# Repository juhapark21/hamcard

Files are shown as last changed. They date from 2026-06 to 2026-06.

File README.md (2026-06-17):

# Ham radio card 
A small dashboard that displays propagation conditions with colored LEDs. 

SS 2026-06-11 at 5 26 39 PM
SS 2026-06-11 at 5 27 05 PM
SS 2026-06-11 at 5 27 47 PM

## How to use 
Replace the placeholder values in the firmware with the SSID and password of your known wifi network. This makes it so that the microcontroller can connect to a network and access the weather data online.  

Assemble the PCB. Components are sized to be possible to hand-solder - A few components are through-hole for ease of hand-soldering.  

After assembling the PCB, flash the firmware onto the XIAO ESP32C3 ([instructions here](https://wiki.seeedstudio.com/xiao_esp32c3_with_micropython/)). 

Connect the ESP32 to a power source via USB-C and turn the power switch ON. The indicator light on the bottom right corner will turn on. 

As long as the board is connected to a network and a power source, it will update its data every hour and the indicator lights will change accordingly. 

LED indicator lights ordered by general severity: 
- Green: Good-Great
- Yellow: Fair
- Orange: Fair-Poor
- Red: Poor 

To turn off, turn the power switch OFF then disconnect the board from the power source. 

## Why 
Propagation info like this is like the weather report for radio nerds. It helps determine which bands you should work, or approximately how far your signal will reach. 

I initially made it because I wanted a fun useful business card. That idea got a bit out of hand (the thickness and power consumption of this does not make it very suitable to be used as a card), but I ended up with a nice physical dashboard showing useful weather information for amateur radio. 

Most existing dashboards are online, so I wanted this to be a physical object separate from tabs or apps on my computer. 

## Process 
The design and build process is documented in detail [here](https://fallout.hackclub.com/projects/3668). Even though this project was smaller-scale, it involved a lot of trial-and-error. 

## Credits  
Thank you Paul N0NBH for the solar-terrestrial [data](https://www.hamqsl.com/).  

## Zine page 
Zine - radiocard

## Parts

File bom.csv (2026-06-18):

Index | Quantity | Part Number | Manufacturer Part Number | Description | Link | Available | Backorder | Unit Price | Extended Price USD
1 | 1 | 1597-113991054-ND | 113991054 | XIAO ESP32C3 | https://www.digikey.com/en/products/detail/seeed-technology-co-ltd/113991054/16652880 | 1 | 0 | 4.99000 | 4.99
2 | 2 | 2057-PH1-07-UA-ND | PH1-07-UA | CONN HEADER VERT 7POS 2.54MM | https://www.digikey.com/en/products/detail/adam-tech/PH1-07-UA/9830505 | 2 | 0 | 0.10000 | 0.20
3 | 4 | 1727-2821-1-ND | 74HC595D,118 | IC SHFT REG TRI-STATE 8BIT 16-SO | https://www.digikey.com/en/products/detail/nexperia-usa-inc/74HC595D-118/763087 | 4 | 0 | 0.25000 | 1.00
4 | 1 | 2223-SLW-883935-2A-D-ND | SLW-883935-2A-D | SWITCH SLIDE SPDT 0.5A 30V | https://www.digikey.com/en/products/detail/same-sky-formerly-cui-devices/SLW-883935-2A-D/21259966 | 1 | 0 | 0.47000 | 0.47
5 | 13 | RNCP1206FTD100RCT-ND | RNCP1206FTD100R | RES 100 OHM 1% 1/2W 1206 | https://www.digikey.com/en/products/detail/stackpole-electronics-inc/RNCP1206FTD100R/2240316 | 13 | 0 | 0.01800 | 0.23
6 | 4 | 399-C1206C104K5RACTUCT-ND | C1206C104K5RACTU | CAP CER 0.1UF 50V X7R 1206 | https://www.digikey.com/en/products/detail/kemet/C1206C104K5RACTU/411248 | 4 | 0 | 0.11000 | 0.44
7 | 3 | 160-1406-1-ND | LTST-C150KSKT | LED YELLOW CLEAR 1206 SMD | https://www.digikey.com/en/products/detail/liteon/LTST-C150KSKT/386763 | 3 | 0 | 0.14000 | 0.42
8 | 3 | 160-1405-1-ND | LTST-C150KRKT | LED RED CLEAR 1206 SMD | https://www.digikey.com/en/products/detail/liteon/LTST-C150KRKT/386761 | 3 | 0 | 0.15000 | 0.45
9 | 3 | 160-1403-1-ND | LTST-C150KFKT | LED ORANGE CLEAR 1206 SMD | https://www.digikey.com/en/products/detail/liteon/LTST-C150KFKT/386758 | 3 | 0 | 0.15000 | 0.45
10 | 4 | 160-1404-1-ND | LTST-C150KGKT | LED GREEN CLEAR 1206 SMD | https://www.digikey.com/en/products/detail/liteon/LTST-C150KGKT/365085 | 4 | 0 | 0.16000 | 0.64
11 | 10 | 160-1172-1-ND | LTST-C155GEKT | LED GREEN/RED CLEAR CHIP SMD | https://www.digikey.com/en/products/detail/liteon/LTST-C155GEKT/269219 | 10 | 0 | 0.15300 | 1.53
12 | 16 | RNCP1206FTD200RCT-ND | RNCP1206FTD200R | RES 200 OHM 1% 1/2W 1206 | https://www.digikey.com/en/products/detail/stackpole-electronics-inc/RNCP1206FTD200R/2240320 | 16 | 0 | 0.01800 | 0.29
Total cost |  |  |  |  |  |  |  |  | 11.11

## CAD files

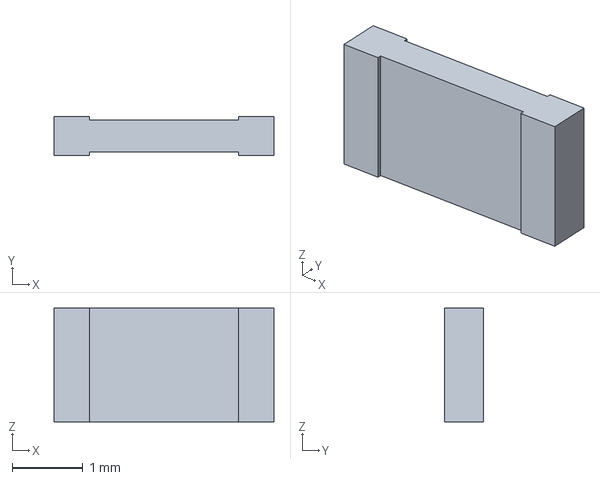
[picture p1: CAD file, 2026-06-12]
pcb/ProjectSpecificResources/crm1206.stp
3.10 x 0.55 x 1.60 mm

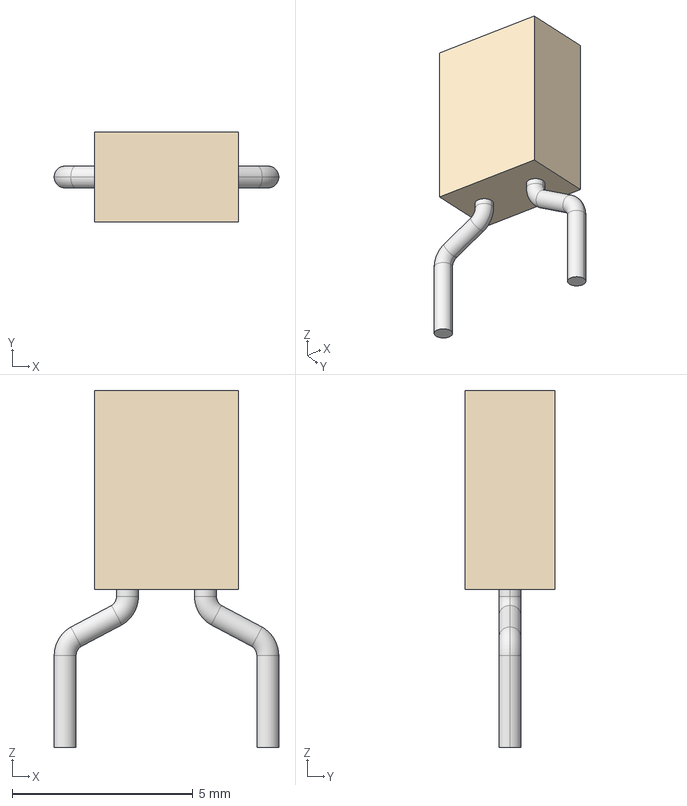
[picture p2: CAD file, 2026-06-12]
pcb/ProjectSpecificResources/CAP_FG28_TDK.step
6.22 x 2.49 x 9.88 mm

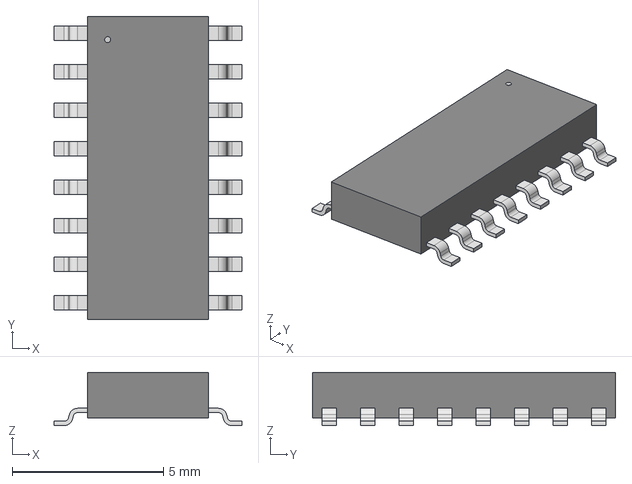
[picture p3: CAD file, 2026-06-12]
pcb/ProjectSpecificResources/SOT109-1_NXP.step
6.20 x 10.0 x 1.75 mm

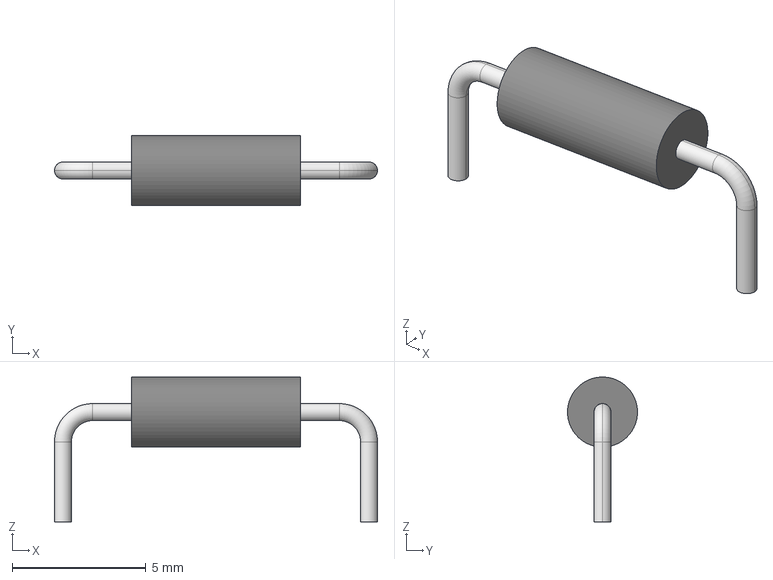
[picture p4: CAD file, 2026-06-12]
pcb/ProjectSpecificResources/STA_CFM12_STP.step
12.1 x 2.61 x 5.41 mm

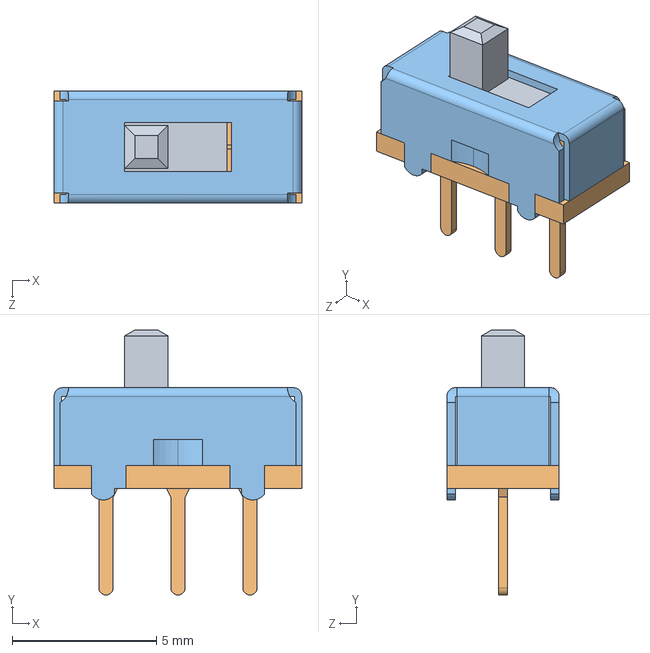
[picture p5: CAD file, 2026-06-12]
pcb/ProjectSpecificResources/Same_Sky_SLW-883935-2A-D.step
8.60 x 9.20 x 3.90 mm

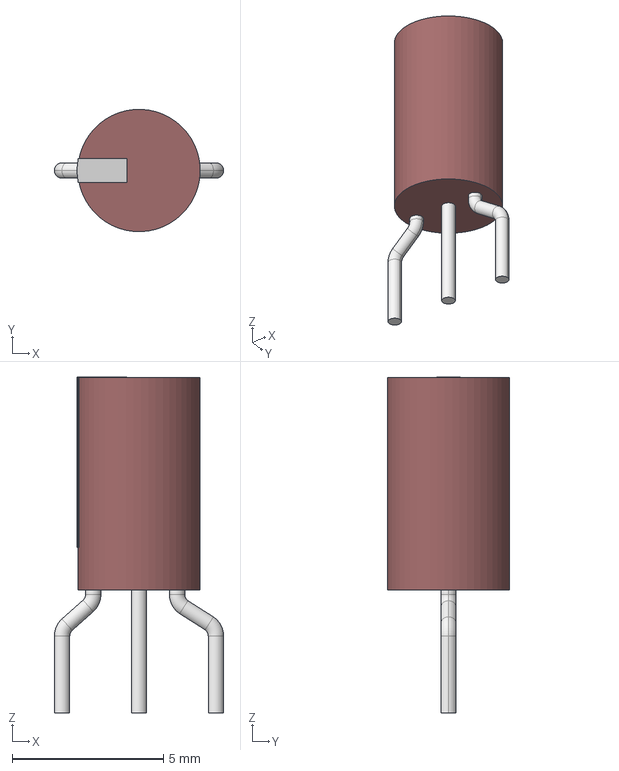
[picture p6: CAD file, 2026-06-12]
pcb/ProjectSpecificResources/LTL-LED3_LTO.step
5.59 x 4.04 x 11.1 mm

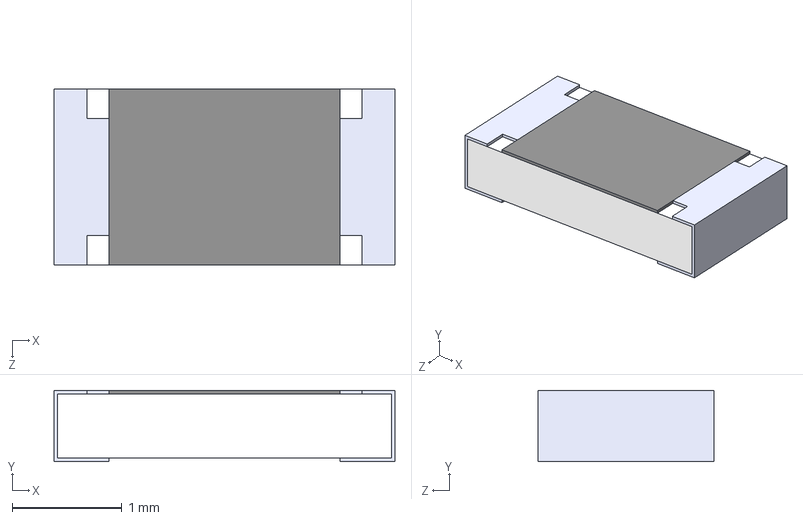
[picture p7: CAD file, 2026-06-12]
pcb/ProjectSpecificResources/CRM1206-FX-33R0ELF.step
3.10 x 0.65 x 1.60 mm

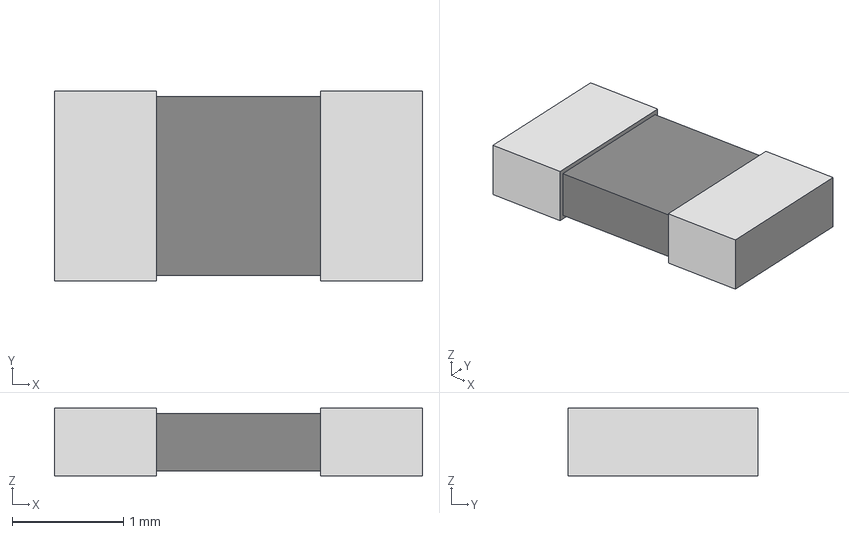
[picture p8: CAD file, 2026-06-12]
pcb/ProjectSpecificResources/STA_RNCP1206_STP.step
3.30 x 1.70 x 0.61 mm

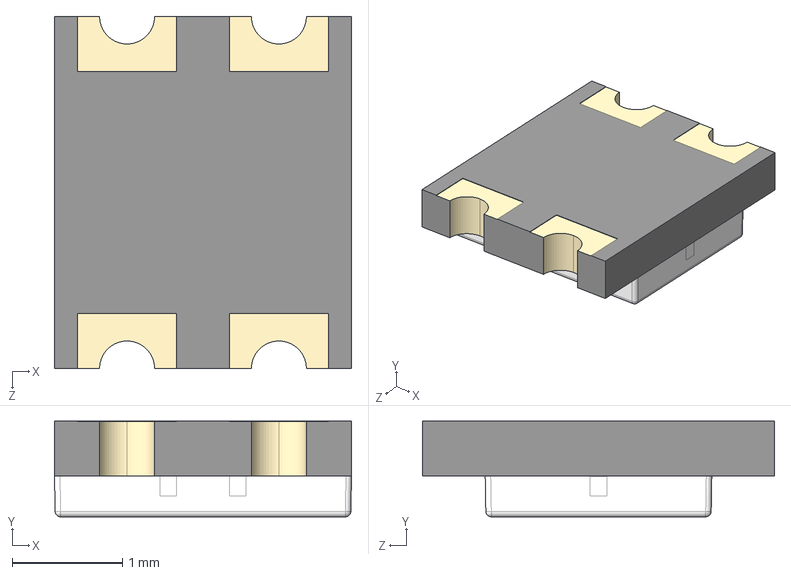
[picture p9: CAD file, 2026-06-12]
pcb/ProjectSpecificResources/LTST-C155GEKT.stp
2.70 x 0.87 x 3.20 mm

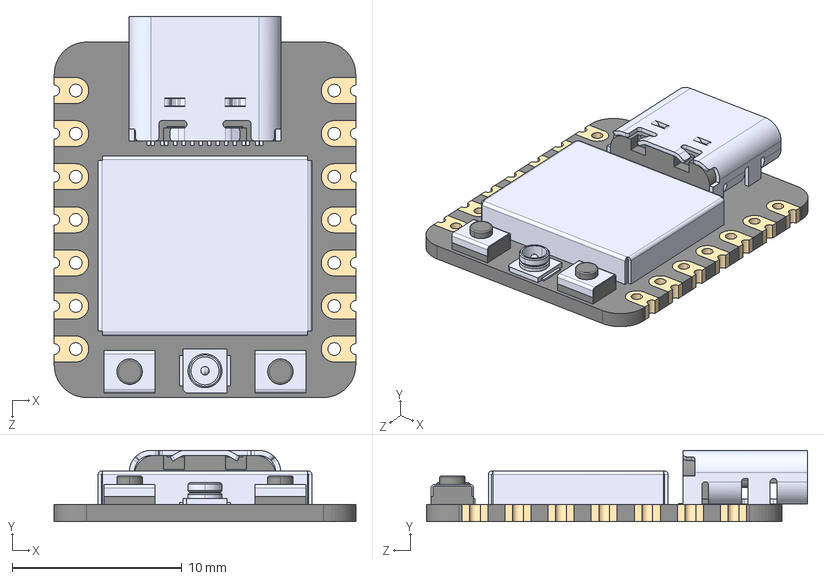
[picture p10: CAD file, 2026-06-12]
pcb/ProjectSpecificResources/113991054.STEP
17.8 x 4.21 x 22.5 mm

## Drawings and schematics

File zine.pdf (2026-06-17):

# HAM RADIO (BUSINESS) CARD!!

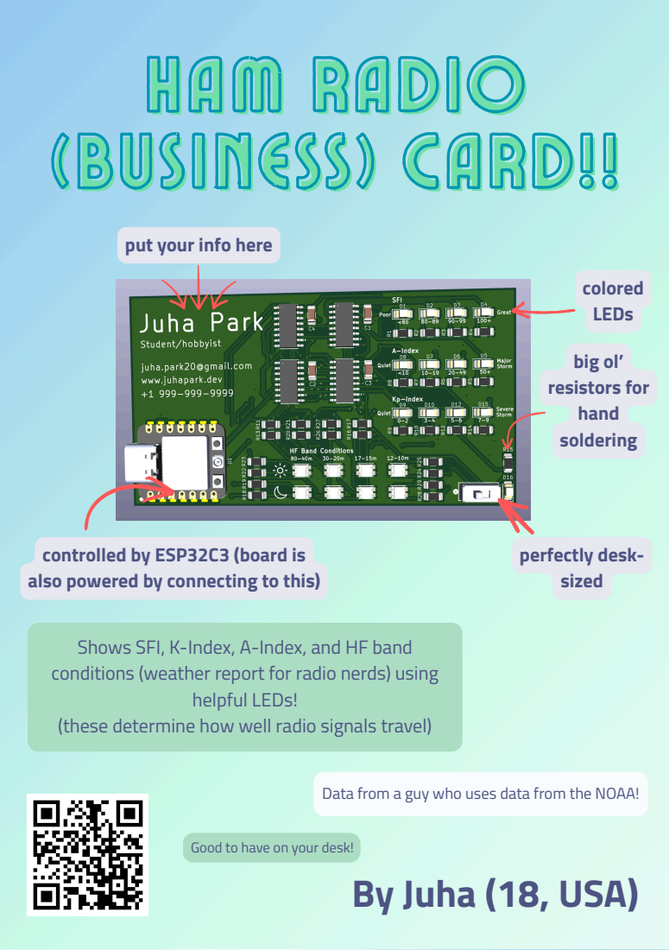
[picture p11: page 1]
colored LEDs; big ol’ resistors for hand soldering; perfectly desk- sized; helpful LEDs!; HHAAMM RRAADDIIOO ((BBUUSSIINNEESSSS)) CCAARRDD!!!!

put your info here

controlled by ESP32C3 (board is
also powered by connecting to this)

Shows SFI, K-Index, A-Index, and HF band
conditions (weather report for radio nerds) using

(these determine how well radio signals travel)

Data from a guy who uses data from the NOAA!
By Juha (18, USA)

Good to have on your desk!

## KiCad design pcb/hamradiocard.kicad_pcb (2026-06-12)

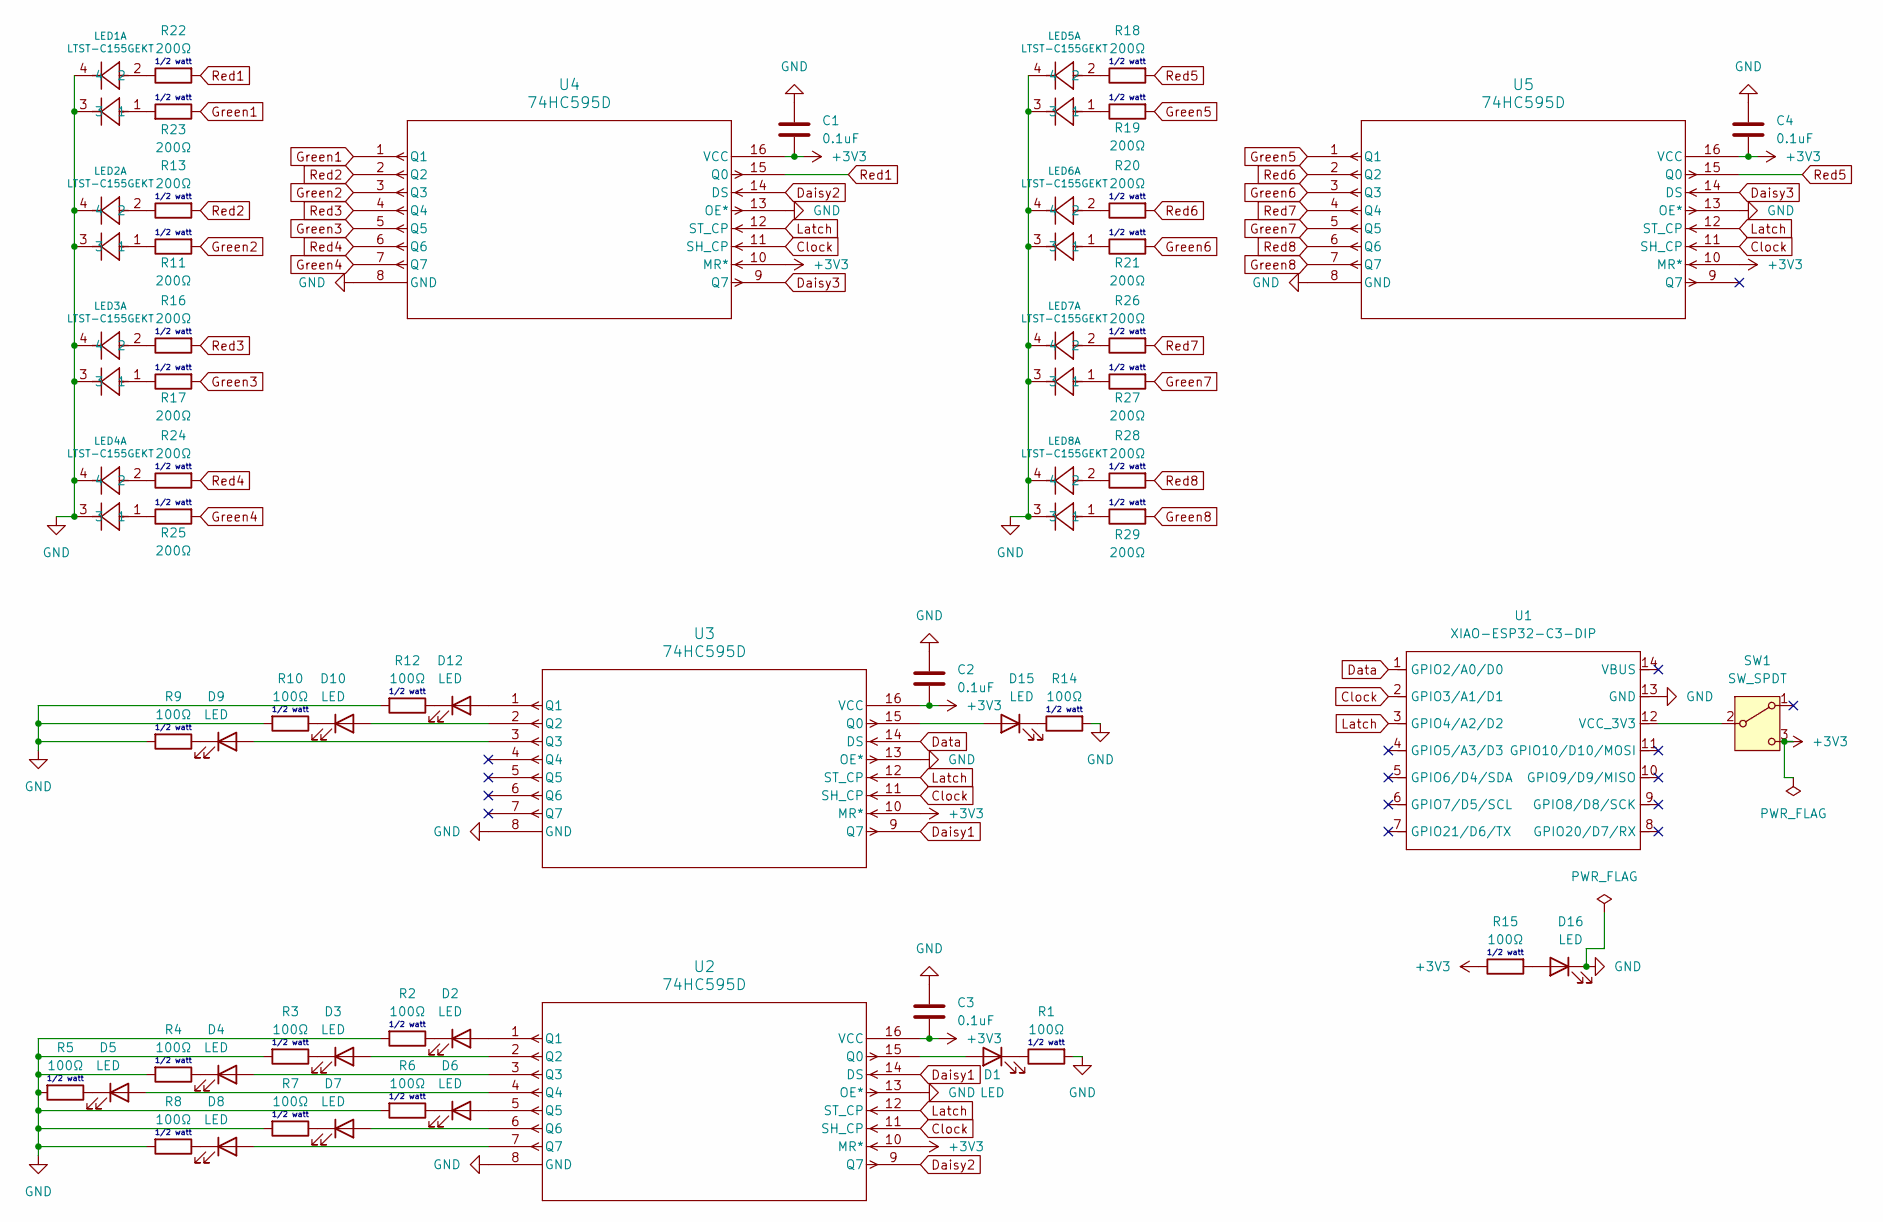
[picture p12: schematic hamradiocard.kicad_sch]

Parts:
C1, C2, C3, C4: 0.1uF; C_1206_3216Metric_Pad1.33x1.80mm_HandSolder
D1, D2, D3, D4, D5, D6, D7, D8, D9, D10, D12, D15, D16: LED; LED_1206_3216Metric_Pad1.42x1.75mm_HandSolder
LED1, LED2, LED3, LED4, LED5, LED6, LED7, LED8: LTST-C155GEKT; DIODE_LTST-C155GEKT_LTO-M
R1, R2, R3, R4, R5, R6, R7, R8, R9, R10, R12, R14, R15: 100Ω; R_1206_3216Metric_Pad1.30x1.75mm_HandSolder
R11, R13, R16, R17, R18, R19, R20, R21, R22, R23, R24, R25, R26, R27, R28, R29: 200Ω; R_1206_3216Metric_Pad1.30x1.75mm_HandSolder
SW1: SW_SPDT; SW3_SLW-883935-2A-D_SSY
U1: XIAO-ESP32-C3-DIP; XIAO-ESP32C3-DIP
U2, U3, U4, U5: 74HC595D; SOT109-1_NXP

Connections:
+3V3: C1.2, C2.2, C3.2, C4.2, R15.1, SW1.3 (C), U2.10 (MR*), U2.16 (VCC), U3.10 (MR*), U3.16 (VCC), U4.10 (MR*), U4.16 (VCC), U5.10 (MR*), U5.16 (VCC)
Clock: U1.2 (GPIO3/A1/D1), U2.11 (SH_CP), U3.11 (SH_CP), U4.11 (SH_CP), U5.11 (SH_CP)
Daisy1: U2.14 (DS), U3.9 (Q7)
Daisy2: U2.9 (Q7), U4.14 (DS)
Daisy3: U4.9 (Q7), U5.14 (DS)
Data: U1.1 (GPIO2/A0/D0), U3.14 (DS)
GND: C1.1, C2.1, C3.1, C4.1, D16.1 (K), LED1.3, LED1.4, LED2.3, LED2.4, LED3.3, LED3.4, LED4.3, LED4.4, LED5.3, LED5.4, LED6.3, LED6.4, LED7.3, LED7.4, LED8.3, LED8.4, R1.2, R2.2, R3.2, R4.2, R5.2, R6.2, R7.2, R8.2, R9.2, R10.2, R12.2, R14.2, U1.13 (GND), U2.8 (GND), U2.13 (OE*), U3.8 (GND), U3.13 (OE*), U4.8 (GND), U4.13 (OE*), U5.8 (GND), U5.13 (OE*)
Green1: R23.1, U4.1 (Q1)
Green2: R11.2, U4.3 (Q3)
Green3: R17.2, U4.5 (Q5)
Green4: R25.2, U4.7 (Q7)
Green5: R19.2, U5.1 (Q1)
Green6: R21.2, U5.3 (Q3)
Green7: R27.2, U5.5 (Q5)
Green8: R29.2, U5.7 (Q7)
Latch: U1.3 (GPIO4/A2/D2), U2.12 (ST_CP), U3.12 (ST_CP), U4.12 (ST_CP), U5.12 (ST_CP)
unnamed: D1.2 (A), U2.15 (Q0)
unnamed: D1.1 (K), R1.1
unnamed: D2.2 (A), U2.1 (Q1)
unnamed: D2.1 (K), R2.1
unnamed: D3.2 (A), U2.2 (Q2)
unnamed: D3.1 (K), R3.1
unnamed: D4.2 (A), U2.3 (Q3)
unnamed: D4.1 (K), R4.1
unnamed: D5.2 (A), U2.4 (Q4)
unnamed: D5.1 (K), R5.1
unnamed: D6.2 (A), U2.5 (Q5)
unnamed: D6.1 (K), R6.1
unnamed: D7.2 (A), U2.6 (Q6)
unnamed: D7.1 (K), R7.1
unnamed: D8.2 (A), U2.7 (Q7)
unnamed: D8.1 (K), R8.1
unnamed: D9.2 (A), U3.3 (Q3)
unnamed: D9.1 (K), R9.1
unnamed: D10.2 (A), U3.2 (Q2)
unnamed: D10.1 (K), R10.1
unnamed: D12.2 (A), U3.1 (Q1)
unnamed: D12.1 (K), R12.1
unnamed: D15.2 (A), U3.15 (Q0)
unnamed: D15.1 (K), R14.1
unnamed: D16.2 (A), R15.2
unnamed: LED1.1, R23.2
unnamed: LED1.2, R22.1
unnamed: LED2.1, R11.1
unnamed: LED2.2, R13.1
unnamed: LED3.1, R17.1
unnamed: LED3.2, R16.1
unnamed: LED4.1, R25.1
unnamed: LED4.2, R24.1
unnamed: LED5.1, R19.1
unnamed: LED5.2, R18.1
unnamed: LED6.1, R21.1
unnamed: LED6.2, R20.1
unnamed: LED7.1, R27.1
unnamed: LED7.2, R26.1
unnamed: LED8.1, R29.1
unnamed: LED8.2, R28.1
unnamed: SW1.2 (B), U1.12 (VCC_3V3)
Red1: R22.2, U4.15 (Q0)
Red2: R13.2, U4.2 (Q2)
Red3: R16.2, U4.4 (Q4)
Red4: R24.2, U4.6 (Q6)
Red5: R18.2, U5.15 (Q0)
Red6: R20.2, U5.2 (Q2)
Red7: R26.2, U5.4 (Q4)
Red8: R28.2, U5.6 (Q6)

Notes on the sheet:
1/2 watt

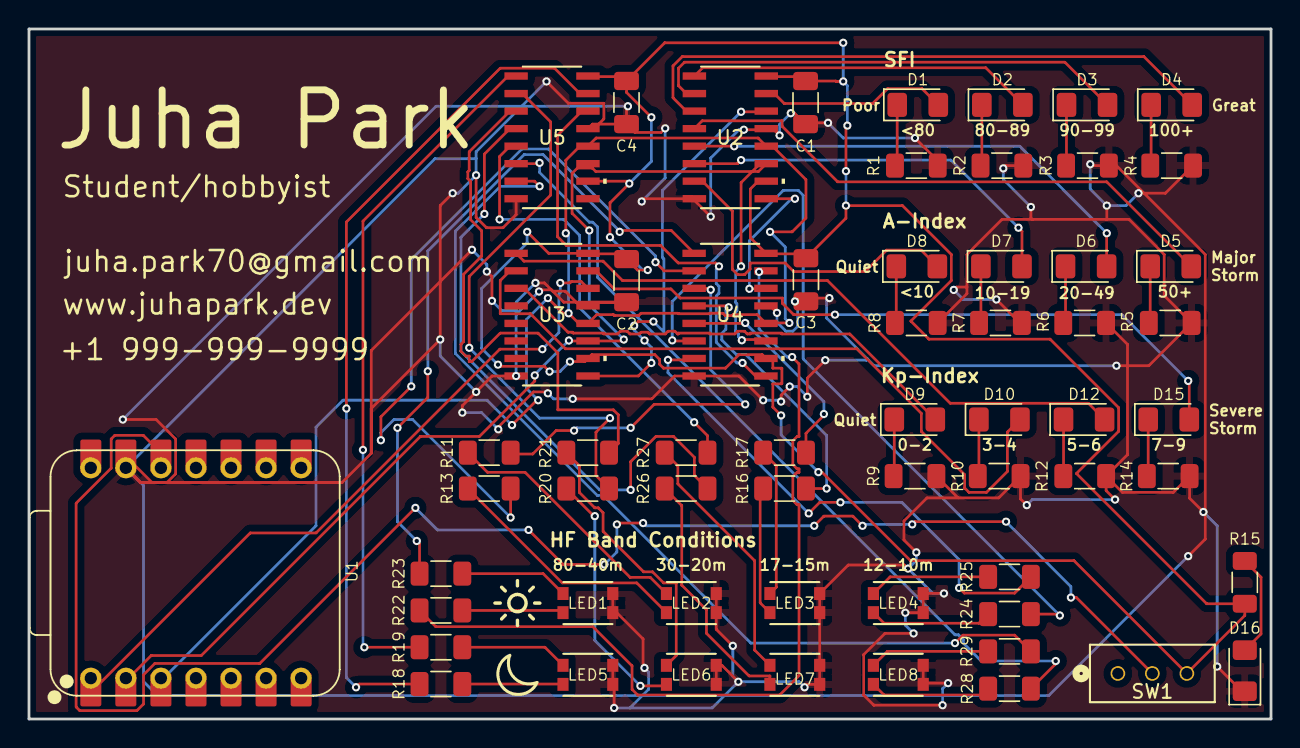
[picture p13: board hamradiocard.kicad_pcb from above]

Board: 2 copper layers, 90.0 x 50.0 mm, 60 parts (0 on the bottom side), 66 nets.

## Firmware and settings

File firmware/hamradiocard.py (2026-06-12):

import network
import time
import requests
from machine import Pin

# https://wiki.seeedstudio.com/xiao_esp32c3_with_micropython/
# will hang until successful connection made 
def do_connect():
    wlan = network.WLAN(network.STA_IF)
    wlan.active(True)
    if not wlan.isconnected():
        print('connecting to network...')
        wlan.connect('SSID', 'KEY') #replace the ssid and key.
        # I really don't want to show my wifi password in my firmware so it's left as a placeholder for now
        while not wlan.isconnected():
            time.sleep(1) 
            pass
    print('network config:', wlan.ifconfig())

def getjson(url):
    response = requests.get(url)
    response_code = response.status_code
    print('Response code: ', response_code)
    response_data = response.json()
    response.close() 
    return response_data  

def getSpecialTagVal(data, start_tag, end_tag):
    try:
        if data.find(start_tag) == -1:
            start_ind = -1
        else: 
            start_ind = data.find(start_tag) + len(start_tag)
        end_ind = data.find(end_tag)
        
        if start_ind != -1 and end_ind != -1:
            value = data[start_ind:end_ind]
            return value
        else:
            print('Tag not found in xml response')
            return -1 
    except Exception as e:
        print('Parsing error: ', e)
        return -1 

def getTagVal(data, tag):
    start_tag = tag
    end_tag = "</" + tag[1:] 
    return getSpecialTagVal(data, start_tag, end_tag)

def getHFVal(data, r, c):
    timeOfDay = ''
    bandnames = {
        0: '80m-40m',
        1: '30m-20m',
        2: '17m-15m',
        3: '12m-10m' 
    }
    
    if r == 0:
        # Daytime
        timeOfDay = 'day'
    else:
        # Nighttime
        timeOfDay = 'night'
    
    longtag = '<band name="' + bandnames[c] + '" time="' + timeOfDay + '">'
    return getSpecialTagVal(data, longtag, '</band>') 

# Set up network connection and pins 
do_connect()

dataPin = Pin(2, Pin.OUT)
latchPin = Pin(4, Pin.OUT)
clockPin = Pin(3, Pin.OUT) 

# Loop
while True:
    # Get data 
    url = 'https://www.hamqsl.com/solarxml.php'

    k_ind = -1
    sfi = -1
    a_ind = -1
    #       80-40  30-20  17-15  12-10
    # Day  |_____|_______|______|______
    # Night|     |       |      |
    hfconditions = [
        ["", "", "", ""],
        ["", "", "", ""]
    ]

    try:
        response = requests.get(url)
        response_code = response.status_code
        print('Response code: ', response_code)
        # Text for xml 
        data = response.text 
        response.close()  
        
        if data:
            sfi = int(getTagVal(data, '<solarflux>'))
            a_ind = int(getTagVal(data, '<aindex>'))
            k_ind = int(getTagVal(data, '<kindex>'))
            
            for r in range(0, 2):
                for c in range(0, 4):
                    hfconditions[r][c] = getHFVal(data, r, c)
            
        else:
            print('No data found in solarxml.php')
    except Exception as e:
        print('An error occurred during the request: ', str(e)) 

    # Display data
    # https://wokwi.com/projects/396045549702862849
    
    #U3 - 4 for Kp and 4 empty 
    kp_disp = [0, 0, 0, 0]
    if k_ind >= 7:
        kp_disp[3] = 1
    elif k_ind >= 5:
        kp_disp[2] = 1
    elif k_ind >= 3:
        kp_disp[1] = 1
    elif k_ind <= 2:
        kp_disp[0] = 1 

    #U2 - 4 for sfi and 4 for A 
    sfi_disp = [0, 0, 0, 0]
    if sfi < 80:
        sfi_disp[0] = 1
    elif sfi < 90:
        sfi_disp[1] = 1
    elif sfi < 100:
        sfi_disp[2] = 1
    elif sfi >= 100:
        sfi_disp[3] = 1

    a_disp = [0, 0, 0, 0]
    if a_ind >= 50:
        a_disp[3] = 1
    elif a_ind >= 20:
        a_disp[2] = 1
    elif a_ind >= 10:
        a_disp[1] = 1
    elif a_ind < 10:
        a_disp[0] = 1 

    # U4 - 8 for daytime
    # U5 - 8 for nighttime 
    hf_disp = [
        [[0, 0], [0, 0], [0, 0], [0, 0]],
        [[0, 0], [0, 0], [0, 0], [0, 0]]
    ]

    for r in range(0, 2):
        for c in range(0, 4):
            text = hfconditions[r][c]
            if text == 'Poor':
                # Red light
                hf_disp[r][c][0] = 1
            elif text == 'Good':
                # Green light
                hf_disp[r][c][1] = 1
            elif text == 'Fair':
                # Yellow light
                hf_disp[r][c][0] = 1
                hf_disp[r][c][1] = 1 

    total = kp_disp + [0, 0, 0, 0] + sfi_disp + a_disp + [item for row in hf_disp for pair in row for item in pair]

    latchPin.off()
    for val in reversed(total):
        dataPin.value(val)
        clockPin.off()
        clockPin.on()
    latchPin.on()
    
    time.sleep_ms(600) 


    # Wait an hour
    time.sleep(60 * 60) 

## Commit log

2026-06-12 Organize repository
    [113991054.STEP, CAP_FG28_TDK.step, CRM1206-FX-33R0ELF.step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]
2026-06-14 Update bom
    [bom.csv]
